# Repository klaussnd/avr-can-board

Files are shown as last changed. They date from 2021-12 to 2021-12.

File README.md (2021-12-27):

# Generic AVR CAN board

This project is a generic [AVR](https://en.wikipedia.org/wiki/AVR_microcontrollers) board with [CAN](https://en.wikipedia.org/wiki/CAN_bus) onboard.
It is designed to be a small-size (55mm x 30mm) versatile board for CAN applications.

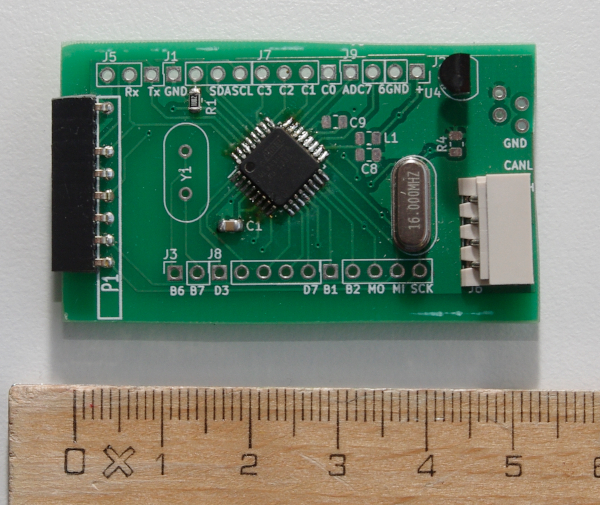
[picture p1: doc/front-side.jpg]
Picture of the front side of the board

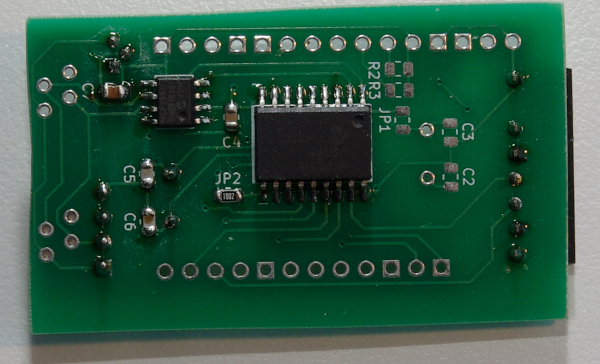
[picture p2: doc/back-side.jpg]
Picture of the back side of the board


The main microcontroller is an ATmega168P or similar (any TQFP32 ATmega can be soldered on the board), for CAN the MCP2515 controller and MCP2551 transceiver are used.
All free pins are routed to the side pin rows (2.54mm spacing), similar to the popular Arduinos.
A voltage regulator (LP2950) is included to use a wide range of voltage sources, typically 12V or 24V supply voltage goes along with the CAN bus so you can spare an additional power supply.
Basic components are SMD 0805 size, use zero ohm 0805 resistors as bridges.

To save cost and PCB space, there is no onboard programmer; an external programmer must be plugged to flash the MCU.
The board has a connector to program (P1) which fits the [mysmartUSB MK2](https://shop.myavr.com/systemboards%20and%20programmer/mySmartUSB%20MK2%20(Programmer%20und%20Bridge).htm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) but any programmer can be wired.

## Configurable features

The board can be configured in separate ways by soldering or not certain bridges or resistors.

* CAN connector can be either two RJ11 or a Molex SPOX
* MCU clock source:
    - internal clock
    - separate crystal (solder crystal and C2 and C3)
    - clock from the MCP2515 (solder a bridge to JP1 and program the MCP2515 accordingly)
* Possibility of using power-safe mode of the MCP2551: solder JP2 _instead of_ R4 (and program the MCP2515 accordingly)
* Select the edge steepness of the CAN signal by adjusting the value of R4 or JP2 (see [MCP2551 datasheet](https://ww1.microchip.com/downloads/en/DeviceDoc/20001667G.pdf))
* I2C pullup resistors: Solder R2 and R3
* Analogue input circuit if required (L1, C8, C9)

## Cape

A template for a cape (PCB which can be plugged onto the controller board as an extension) is included. Add your own circuit to the cape template.

## Firmware

A few tips:

* The SS pin (B2) of the ATmega _must_ be configured as an output, otherwise the SPI communication with the MCP2515 doesn't work.
* As library for the CAN controller you can use, for example, [avr-canlib](https://github.com/klaussnd/avr-can-lib) or [modm](https://modm.io/).

## License

The circuits are licensed under the terms of the [GNU Affero General Public License](https://www.gnu.org/licenses/agpl-3.0.en.html).

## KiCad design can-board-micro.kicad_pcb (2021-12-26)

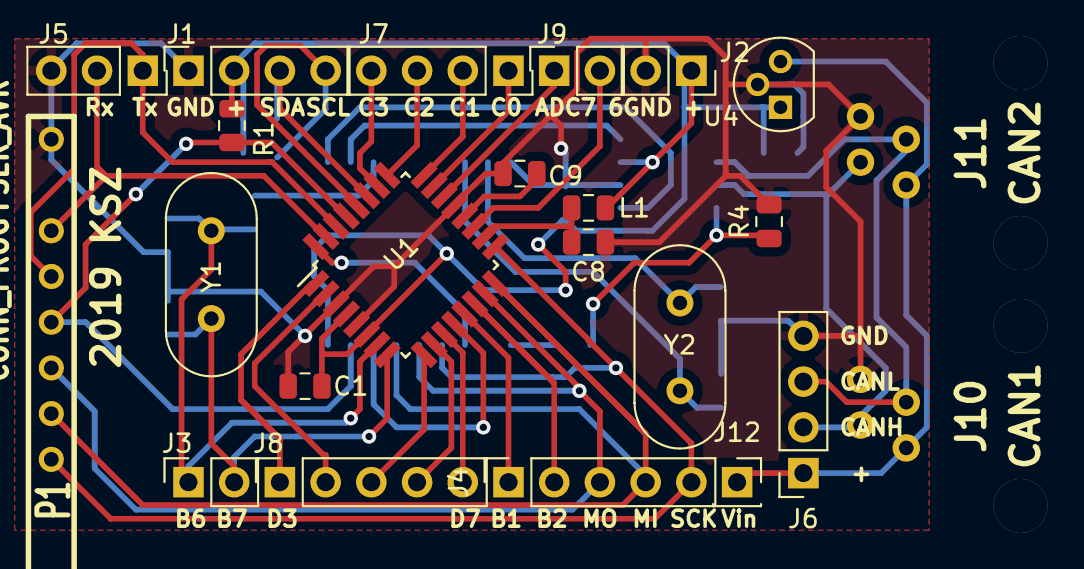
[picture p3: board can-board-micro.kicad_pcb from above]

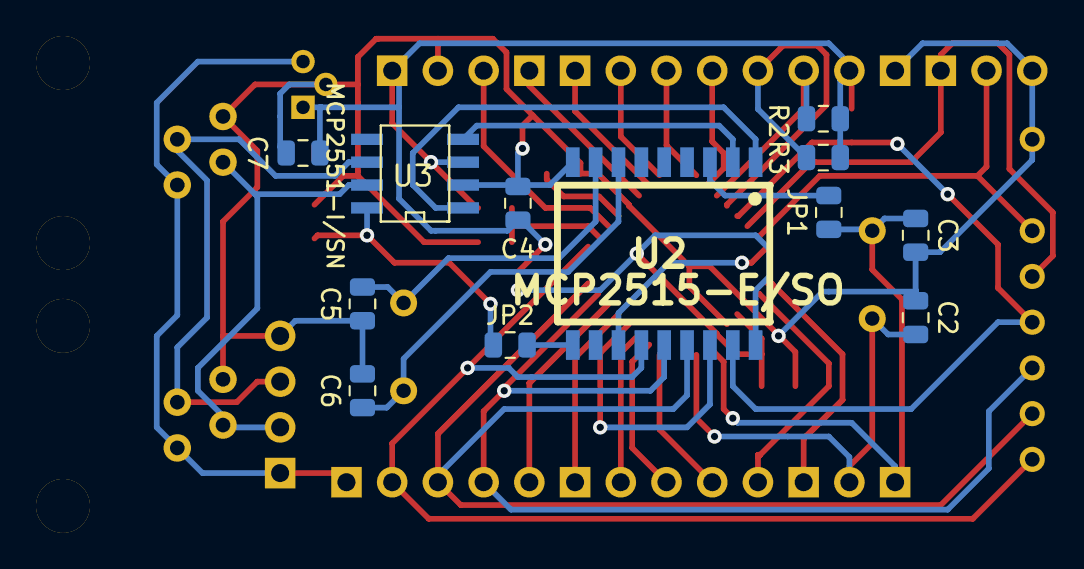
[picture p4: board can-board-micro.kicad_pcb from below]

Board: 2 copper layers, 35 parts (12 on the bottom side), 39 nets.

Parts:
C1, C4, C8, C9: 100n; C_0805_2012Metric
C2, C3: 22p; C_0805_2012Metric
C5, C6: 33p; C_0805_2012Metric
C7: 4.7u; C_0805_2012Metric
J1: I2C; PinSocket_1x04_P2.54mm_Vertical
J2: Vcc; PinSocket_1x02_P2.54mm_Vertical
J3: PORTB_2; PinSocket_1x02_P2.54mm_Vertical
J4: PORTB_1; PinSocket_1x05_P2.54mm_Vertical
J5: USART; PinSocket_1x03_P2.54mm_Vertical
J6: CAN; PinSocket_1x04_P2.54mm_Vertical
J7: PORTC; PinSocket_1x04_P2.54mm_Vertical
J8: PORTD; PinSocket_1x05_P2.54mm_Vertical
J9: ADC; PinSocket_1x02_P2.54mm_Vertical
J10: CAN1; RJ11_RO
J11: CAN2; RJ11_RO
J12: 12V; PinSocket_1x01_P2.54mm_Vertical
JP1: clk; R_0805_2012Metric
JP2: SLEEP; R_0805_2012Metric
L1: 10u; L_0805_2012Metric
P1: CONN_PROG+SER_AVR; SIL-10_MYAVR+SER
R1, R4: 10k; R_0805_2012Metric
R2, R3: 4.7k; R_0805_2012Metric
U1: ATMEGA168PA-AU; TQFP-32_7x7mm_P0.8mm
U2: MCP2515-E/SO; SOIC18_300
U3: MCP2551-I/SN; SOIC8_150
U4: LP2950-5.0_TO92; TO-92
Y1: 7.3728MHz; Crystal_HC49-U_Vertical
Y2: 16MHz; Crystal_HC49-U_Vertical

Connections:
/SCL: J1.4, R3.2, U1.28
/SDA: J1.3, R2.2, U1.27
GNDD: C1.2, C2.2, C3.2, C4.2, C5.2, C6.2, C7.2, C8.2, C9.2, J1.1, J2.2, J5.3, J6.4, J10.5, J11.5, P1.10, R4.2, U1.3, U1.5, U1.21, U2.9, U3.2, U4.2
unnamed: C2.1, J3.2, U1.8, Y1.2
unnamed: C3.1, J3.1, JP1.1, U1.7, Y1.1
unnamed: C5.1, U2.8, Y2.2
unnamed: C6.1, U2.7, Y2.1
unnamed: C8.1, L1.2, U1.18
unnamed: C9.1, U1.20
unnamed: J4.1, U1.13
unnamed: J4.2, U1.14
unnamed: J4.3, P1.5, U1.15, U2.14
unnamed: J4.4, P1.4, U1.16, U2.15
unnamed: J4.5, P1.3, U1.17, U2.13
unnamed: J5.1, P1.7, U1.30
unnamed: J5.2, P1.8, U1.31
unnamed: J7.1, U1.23
unnamed: J7.2, U1.24
unnamed: J7.3, U1.25
unnamed: J7.4, U1.26
unnamed: J8.1, U1.1
unnamed: J8.2, U1.2
unnamed: J8.3, U1.9
unnamed: J8.4, U1.10
unnamed: J8.5, U1.11
unnamed: J9.1, U1.22
unnamed: J9.2, U1.19
unnamed: J6.1, J10.2, J11.2, J12.1, U4.3
unnamed: J6.2, J10.3, J11.3, U3.7
unnamed: J6.3, J10.4, J11.4, U3.6
unnamed: JP1.2, U2.3
unnamed: JP2.1, R4.1, U3.8
unnamed: JP2.2, U2.10
unnamed: P1.6, R1.2, U1.29, U2.17
unnamed: U1.12, U2.16
unnamed: U1.32, U2.12
unnamed: U2.1, U3.1
unnamed: U2.2, U3.4
VCC: C1.1, C4.1, C7.1, J1.2, J2.1, L1.1, R1.1, R2.1, R3.1, U1.4, U1.6, U2.18, U3.3, U4.1

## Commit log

2021-12-26 Add micro CAN adapter
    [can-board-micro.kicad_pcb, can-board-micro.sch]
2021-12-26 Add empty cape for micro CAN board
    [can-board-micro-cape.kicad_pcb, can-board-micro-cape.sch]
